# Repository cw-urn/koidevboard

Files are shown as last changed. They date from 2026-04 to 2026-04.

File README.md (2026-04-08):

# koidevboard

> What is this?
- koiboard, but the RP2040 development board version.
> How do you use it?
- Everybody knows how to use a devboard...
> Why did I make this?
- Boredom, and I thought it would be interesting and I'd learn from it. I did!

## 3D render
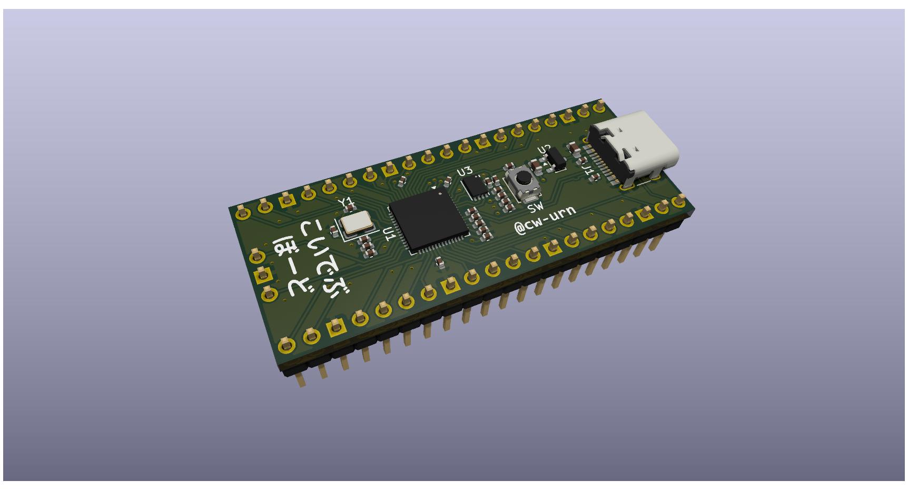
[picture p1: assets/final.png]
3D render


## PCB

### Layer 1
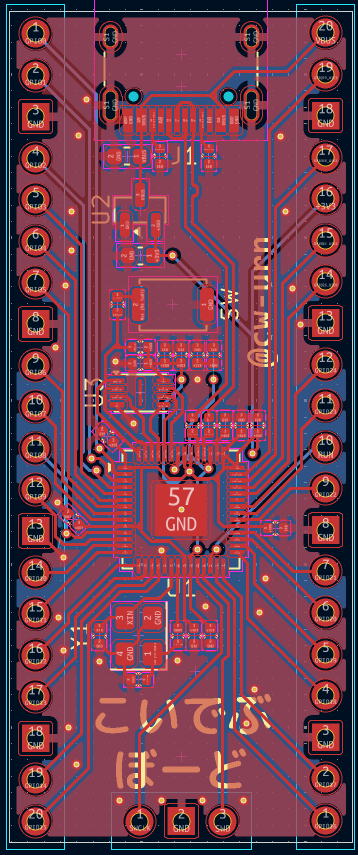
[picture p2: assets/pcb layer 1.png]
Layer 1


### Layer 2
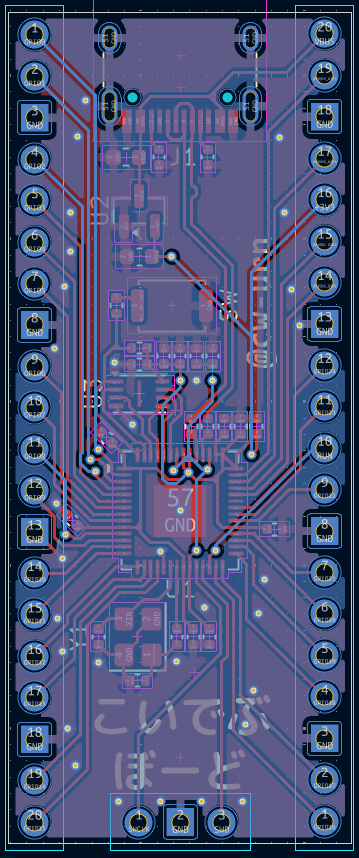
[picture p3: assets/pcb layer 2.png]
Layer 2


### Schematic
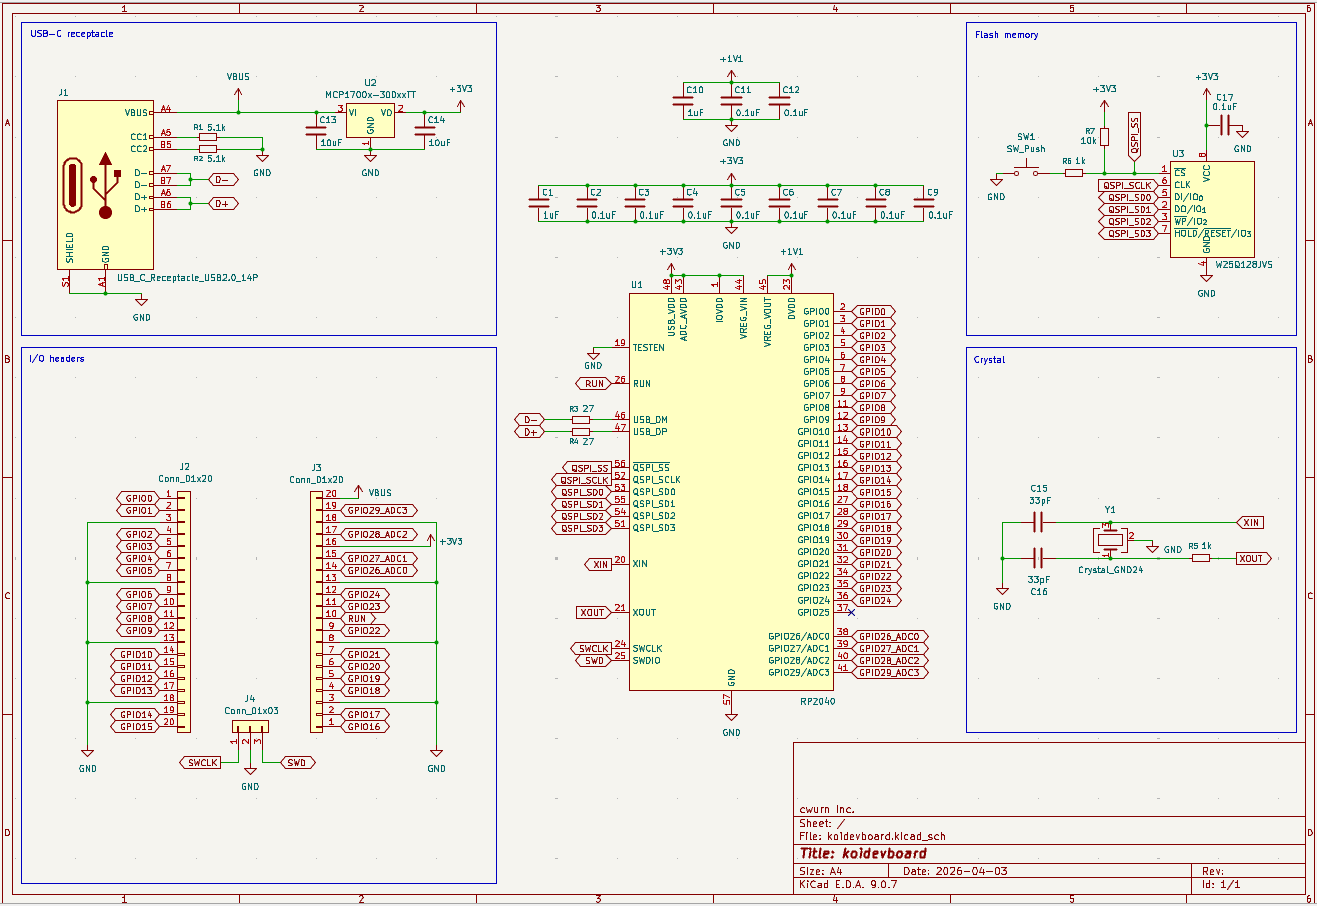
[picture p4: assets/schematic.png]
Schematic


## JLCPCB cart
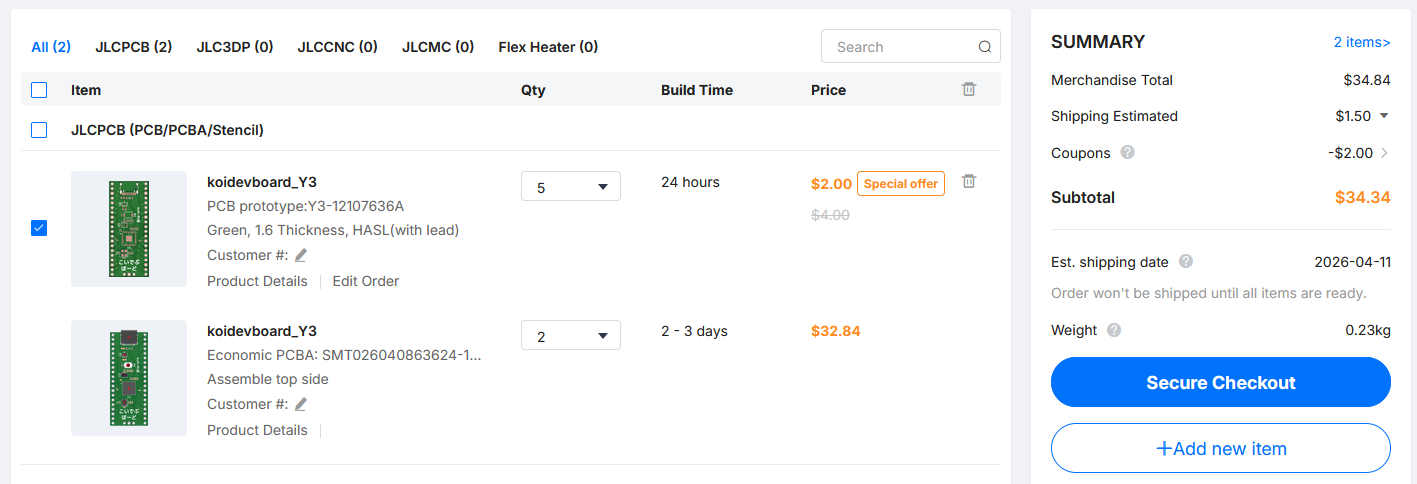
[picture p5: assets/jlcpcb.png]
JLCPCB cart


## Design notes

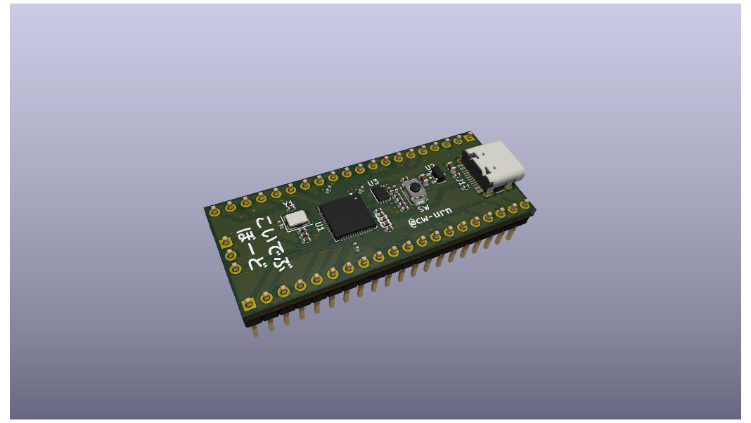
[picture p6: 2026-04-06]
pcb/src/3d render.png

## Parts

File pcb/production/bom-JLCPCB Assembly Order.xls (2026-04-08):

JLCPCB BOM Tool - BOM Matching
BOM name：bom-JLCPCB Assembly Order.xlsx |  |  | Download Time：2026-04-09 04:32:29 |  |  |  | * Our matching results are updated in real-time, but stock and prices may change. If it's been over 24 hours, please re-match before placing your order.
PCB Assembled Qty：5 |  |  | Est. Total Price：6.6379
Your BOM |  |  |  |  | Matched Parts |  |  |  |  |  |  | Order Information
Top Designator | Bottom Designator | Comment | Footprint | JLCPCB Part # | Matches | Part # | Manufacturer | Footprint | Description | Category | Warning | JLCPCB Part # | Product link | Lib Type | Qty | Source | Total Price ($)
C1,C10 |  | 1uF | 0402 |  | Select by System | CL05A105KA5NQNC | Samsung Electro-Mechanics | 0402 | 1uF 25V X5R ±10% 0402 Multilayer Ceramic Capacitors MLCC - SMD/SMT ROHS | Multilayer Ceramic Capacitors MLCC - SMD/SMT |  | C52923 | https://jlcpcb.com/partdetail/53938-CL05A105KA5NQNC/C52923 | Basic | 4 | 4 JLCPCB | 0.0164
C11,C12,C17,C2,C3,C4,C5,C6,C7,C8,C9 |  | 0.1uF | 0402 |  | Unconfirmed | CL05B104KO5NNNC | Samsung Electro-Mechanics | 0402 | 100nF 16V X7R ±10% 0402 Multilayer Ceramic Capacitors MLCC - SMD/SMT ROHS | Multilayer Ceramic Capacitors MLCC - SMD/SMT | 1.The comment (CL05B104KO5NNNC) of this part does not match the one (0.1uF) provided in your BOM. Please confirm; | C1525 | https://jlcpcb.com/partdetail/1877-CL05B104KO5NNNC/C1525 | Basic | 22 | 22 JLCPCB | 0.0286
C13,C14 |  | 10uF | 0603 |  | Select by System | CL10A106KP8NNNC | Samsung Electro-Mechanics | 0603 | 10V 10uF X5R ±10% 0603 Multilayer Ceramic Capacitors MLCC - SMD/SMT ROHS | Multilayer Ceramic Capacitors MLCC - SMD/SMT |  | C19702 | https://jlcpcb.com/partdetail/20411-CL10A106KP8NNNC/C19702 | Basic | 4 | 4 JLCPCB | 0.0316
C15,C16 |  | 33pF | 0402 |  | Select by System | 0402CG330J500NT | FH (Guangdong Fenghua Advanced Tech) | 0402 | 33pF 50V C0G ±5% 0402 Multilayer Ceramic Capacitors MLCC - SMD/SMT ROHS | Multilayer Ceramic Capacitors MLCC - SMD/SMT |  | C1562 | https://jlcpcb.com/partdetail/1914-0402CG330J500NT/C1562 | Basic | 4 | 4 JLCPCB | 0.0048
J1 |  | USB_C_Receptacle_USB2.0_14P | USB_C_Receptacle_HRO_TYPE-C-31-M-12 |  | Select by Customer | TYPE-C-31-M-12 | Korean Hroparts Elec | SMD | -30℃~+80℃ 1 10,000 cycles 16P 20V 5A 7.35mm Female Surface Mount, Right Angle Type-C SMD USB Connectors ROHS | USB Connectors |  | C165948 | https://jlcpcb.com/partdetail/Korean_HropartsElec-TYPE_C_31_M12/C165948 | Extended | 2 | 2 JLCPCB | 0.3654
R1,R2 |  | 5.1k | 0402 |  | Unconfirmed | 0402WGF5101TCE | UNI-ROYAL(Uniroyal Elec) | 0402 | -55℃~+155℃ 5.1kΩ 50V 62.5mW Thick Film Resistor ±1% ±100ppm/℃ 0402 Chip Resistor - Surface Mount ROHS | Chip Resistor - Surface Mount | 1.The comment (0402WGF5101TCE) of this part does not match the one (5.1k) provided in your BOM. Please confirm; | C25905 | https://jlcpcb.com/partdetail/26648-0402WGF5101TCE/C25905 | Basic | 4 | 4 JLCPCB | 0.0032
R3,R4 |  | 27 | 0402 |  | Unconfirmed | 0402WGF270JTCE | UNI-ROYAL(Uniroyal Elec) | 0402 | -55℃~+155℃ 27Ω 50V 62.5mW Thick Film Resistor ±1% ±100ppm/℃ 0402 Chip Resistor - Surface Mount ROHS | Chip Resistor - Surface Mount | 1.The comment (0402WGF270JTCE) of this part does not match the one (27) provided in your BOM. Please confirm; | C25100 | https://jlcpcb.com/partdetail/25843-0402WGF270JTCE/C25100 | Extended | 20 | 20 JLCPCB | 0.016
R5,R6 |  | 1k | 0402 |  | Unconfirmed | 0402WGF1001TCE | UNI-ROYAL(Uniroyal Elec) | 0402 | -55℃~+155℃ 1kΩ 50V 62.5mW Thick Film Resistor ±1% ±100ppm/℃ 0402 Chip Resistor - Surface Mount ROHS | Chip Resistor - Surface Mount | 1.The comment (0402WGF1001TCE) of this part does not match the one (1k) provided in your BOM. Please confirm; | C11702 | https://jlcpcb.com/partdetail/12256-0402WGF1001TCE/C11702 | Basic | 4 | 4 JLCPCB | 0.0028
R7 |  | 10k | 0402 |  | Unconfirmed | 0402WGF1002TCE | UNI-ROYAL(Uniroyal Elec) | 0402 | -55℃~+155℃ 10kΩ 50V 62.5mW Thick Film Resistor ±1% ±100ppm/℃ 0402 Chip Resistor - Surface Mount ROHS | Chip Resistor - Surface Mount | 1.The comment (0402WGF1002TCE) of this part does not match the one (10k) provided in your BOM. Please confirm; | C25744 | https://jlcpcb.com/partdetail/26487-0402WGF1002TCE/C25744 | Basic | 2 | 2 JLCPCB | 0.0024
SW |  | SW_Push | SW_Push_SPST_NO_Alps_SKRK |  | Select by Customer | TS-1088-AR02016 | XUNPU | SMD,4x3mm | -30℃~+80℃ 1.6N 100,000 cycles 12V 2mm 3mm 4mm 50mA Black Round Button SMD(SMT) Tab SPST Surface Mount,Vertical Without Bracket SMD,4x3mm Tactile Switches ROHS | Tactile Switches |  | C720477 | https://jlcpcb.com/partdetail/XUNPU-TS_1088AR02016/C720477 | Basic | 2 | 2 JLCPCB | 0.1078
U1 |  | RP2040 | QFN-56-1EP_7x7mm_P0.4mm_EP3.2x3.2mm |  | Select by Customer | RP2040 | Raspberry Pi | LQFN-56(7x7) | 12bit 133MHz 30 LQFN-56(7x7) Microcontrollers (MCU/MPU/SOC) ROHS | Microcontrollers (MCU/MPU/SOC) |  | C2040 | https://jlcpcb.com/partdetail/RaspberryPi-RP2040/C2040 | Extended | 2 | 2 JLCPCB | 1.948
U2 |  | MCP1700x-300xxTT | SOT-23 |  | Select by Customer | MCP1700T-3302E/TT | Microchip Tech | SOT-23 | -40℃~+125℃@(Tj) 1 1.6uA 178mV@(250mA) 250mA 3.3V 44dB@(100Hz) 6V Fixed Over Temperature Protection、Short Circuit Protection Positive SOT-23 Voltage Regulators - Linear, Low Drop Out (LDO) Regulators ROHS | Voltage Regulators - Linear, Low Drop Out (LDO) Regulators |  | C39051 | https://jlcpcb.com/partdetail/MicrochipTech-MCP1700T_3302ETT/C39051 | Extended | 5 | 5 JLCPCB | 1.8795
U3 |  | W25Q128JVS | Winbond_USON-8-1EP_3x2mm_P0.5mm_EP0.2x1.6mm |  | Select by Customer | W25Q16JVUXIQ | Winbond Elec | USON-8-EP(2x3) | -40℃~+85℃ 100,000 cycles 10uA 133MHz 16Mbit 2.7V~3.6V 20 Years 3ms SPI USON-8-EP(2x3) NOR FLASH ROHS | NOR FLASH | 1.The comment (W25Q16JVUXIQ) of this part does not match the one (W25Q128JVS) provided in your BOM. Please confirm; | C2843335 | https://jlcpcb.com/partdetail/WinbondElec-W25Q16JVUXIQ/C2843335 | Extended | 2 | 2 JLCPCB | 2.085
Y1 |  | Crystal_GND24 | Crystal_SMD_3225-4Pin_3.2x2.5mm |  | Select by Customer | X322512MSB4SI | YXC Crystal Oscillators | SMD3225-4P | -40℃~+85℃ 12MHz 20pF Crystal Oscillator ±10ppm ±20ppm SMD3225-4P Crystals ROHS | Crystals |  | C9002 | https://jlcpcb.com/partdetail/YXC_CrystalOscillators-X322512MSB4SI/C9002 | Basic | 2 | 2 JLCPCB | 0.1464

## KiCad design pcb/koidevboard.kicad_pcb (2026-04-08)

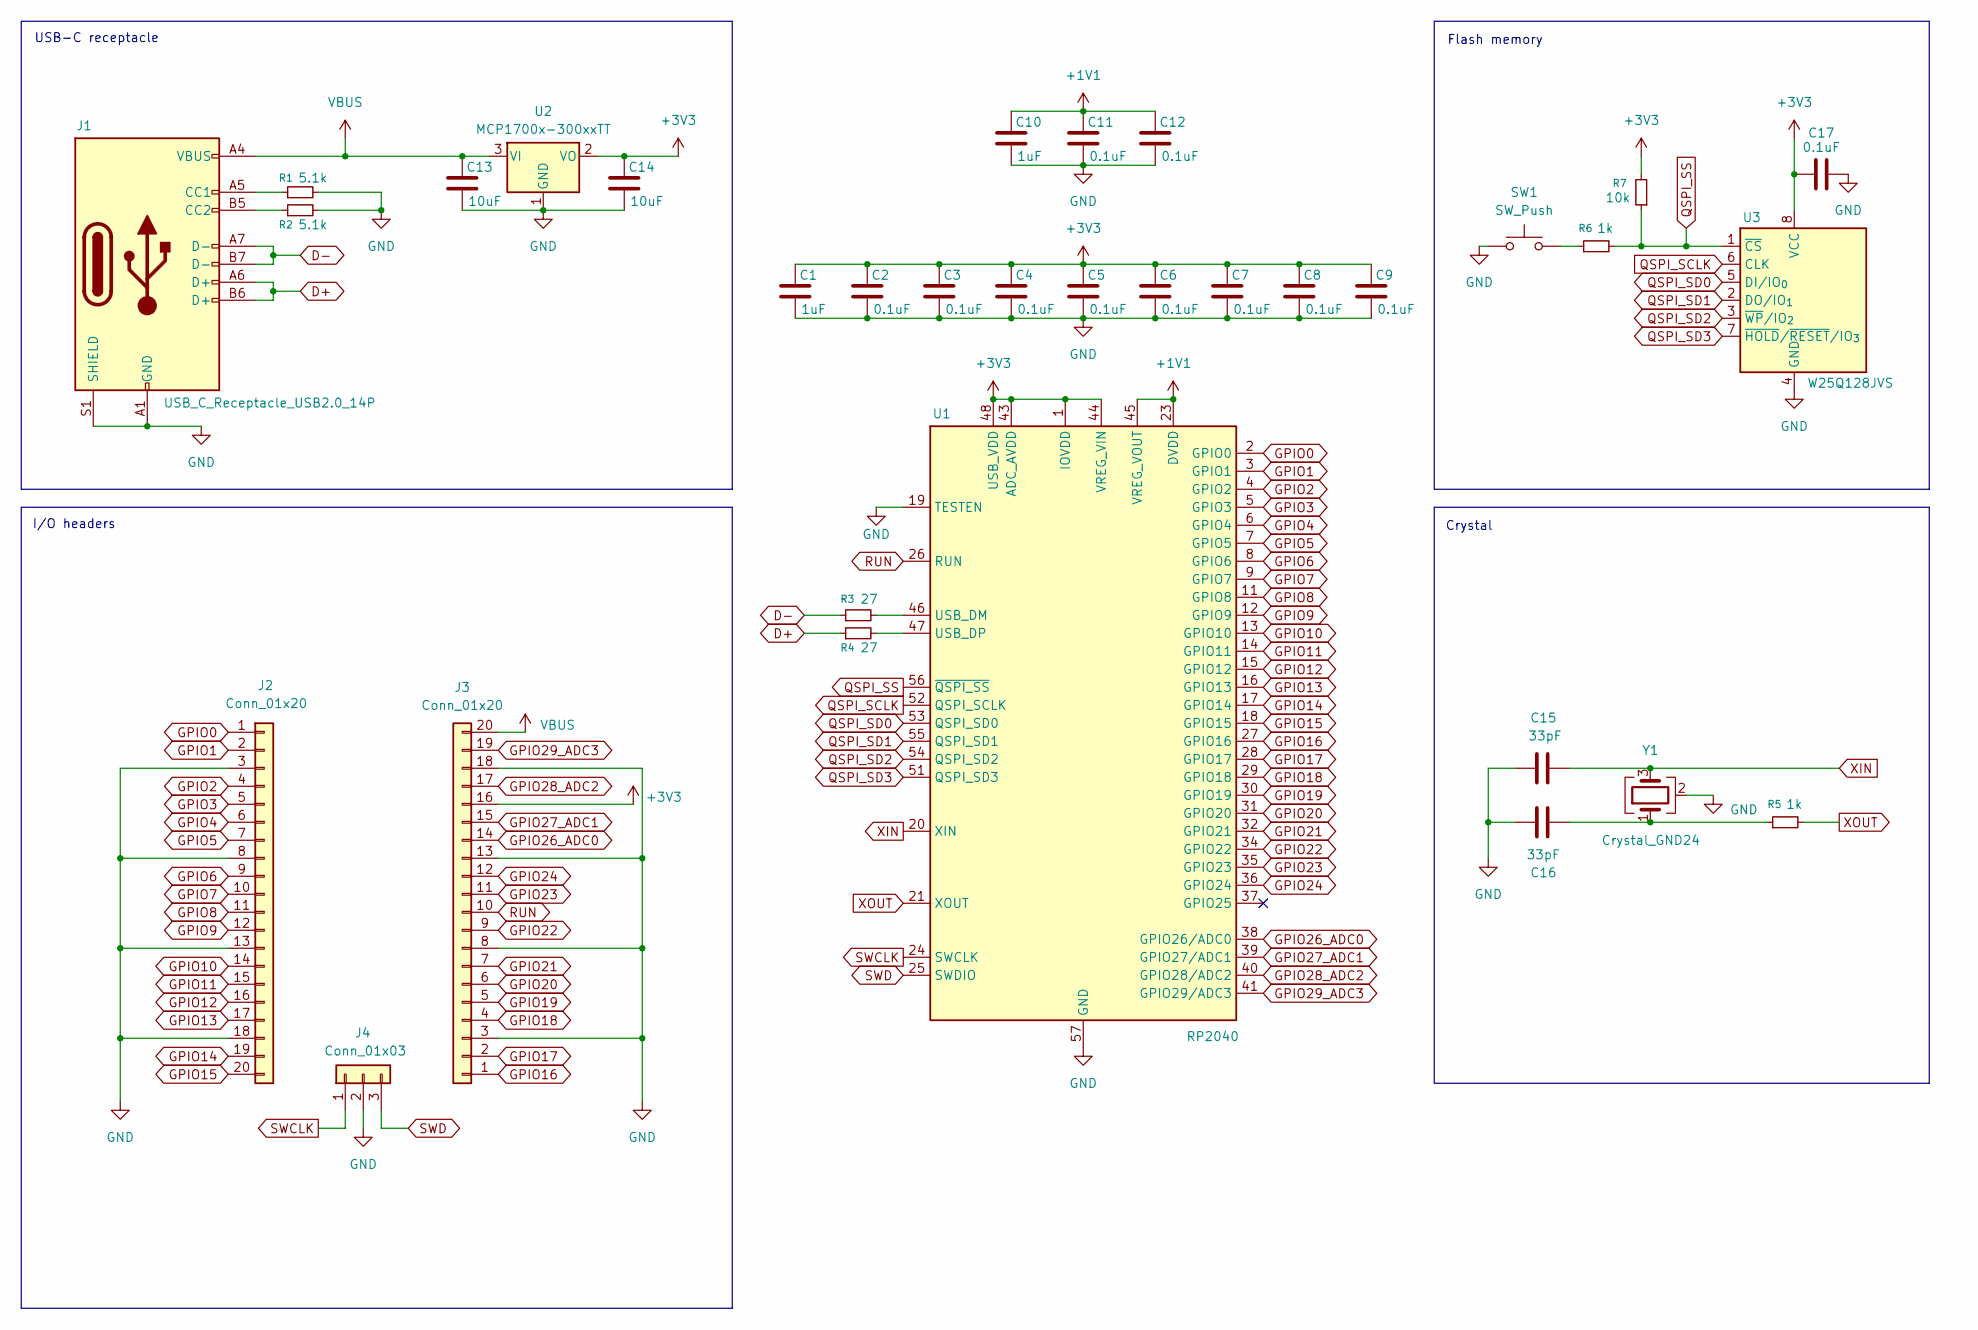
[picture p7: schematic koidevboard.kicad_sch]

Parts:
C1, C10: 1uF; C_0402_1005Metric
C2, C3, C4, C5, C6, C7, C8, C9, C11, C12, C17: 0.1uF; C_0402_1005Metric
C13, C14: 10uF; C_0603_1608Metric
C15, C16: 33pF; C_0402_1005Metric
J1: USB_C_Receptacle_USB2.0_14P; USB_C_Receptacle_HRO_TYPE-C-31-M-12
J2, J3: Conn_01x20; PinHeader_1x20_P2.54mm_Vertical
J4: Conn_01x03; PinHeader_1x03_P2.54mm_Vertical
R1, R2: 5.1k; C_0402_1005Metric
R3, R4: 27; C_0402_1005Metric
R5, R6: 1k; C_0402_1005Metric
R7: 10k; C_0402_1005Metric
SW1: SW_Push; SW_Push_SPST_NO_Alps_SKRK
U1: RP2040; QFN-56-1EP_7x7mm_P0.4mm_EP3.2x3.2mm
U2: MCP1700x-300xxTT; SOT-23
U3: W25Q128JVS; Winbond_USON-8-1EP_3x2mm_P0.5mm_EP0.2x1.6mm
Y1: Crystal_GND24; Crystal_SMD_3225-4Pin_3.2x2.5mm

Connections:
+1V1: C10.1, C11.1, C12.1, U1.23 (DVDD), U1.45 (VREG_VOUT), U1.50 (DVDD)
+3V3: C1.1, C2.1, C3.1, C4.1, C5.1, C6.1, C7.1, C8.1, C9.1, C14.1, C17.1, J3.16, R7.2, U1.1 (IOVDD), U1.10 (IOVDD), U1.22 (IOVDD), U1.33 (IOVDD), U1.42 (IOVDD), U1.43 (ADC_AVDD), U1.44 (VREG_VIN), U1.48 (USB_VDD), U1.49 (IOVDD), U2.2 (VO), U3.8 (VCC)
D+: J1.A6 (D+), J1.B6 (D+), R4.1
D-: J1.A7 (D-), J1.B7 (D-), R3.1
GND: C1.2, C2.2, C3.2, C4.2, C5.2, C6.2, C7.2, C8.2, C9.2, C10.2, C11.2, C12.2, C13.2, C14.2, C15.2, C16.2, C17.2, J1.A1 (GND), J1.A12 (GND), J1.B1 (GND), J1.B12 (GND), J1.S1 (SHIELD), J2.3, J2.8, J2.13, J2.18, J3.3, J3.8, J3.13, J3.18, J4.2, R1.2, R2.2, SW1.1, U1.19 (TESTEN), U1.57 (GND), U2.1 (GND), U3.4 (GND), Y1.2 (G), Y1.4 (G); also elsewhere on the board
GPIO0: J2.1, U1.2 (GPIO0)
GPIO1: J2.2, U1.3 (GPIO1)
GPIO2: J2.4, U1.4 (GPIO2)
GPIO3: J2.5, U1.5 (GPIO3)
GPIO4: J2.6, U1.6 (GPIO4)
GPIO5: J2.7, U1.7 (GPIO5)
GPIO6: J2.9, U1.8 (GPIO6)
GPIO7: J2.10, U1.9 (GPIO7)
GPIO8: J2.11, U1.11 (GPIO8)
GPIO9: J2.12, U1.12 (GPIO9)
GPIO10: J2.14, U1.13 (GPIO10)
GPIO11: J2.15, U1.14 (GPIO11)
GPIO12: J2.16, U1.15 (GPIO12)
GPIO13: J2.17, U1.16 (GPIO13)
GPIO14: J2.19, U1.17 (GPIO14)
GPIO15: J2.20, U1.18 (GPIO15)
GPIO16: J3.1, U1.27 (GPIO16)
GPIO17: J3.2, U1.28 (GPIO17)
GPIO18: J3.4, U1.29 (GPIO18)
GPIO19: J3.5, U1.30 (GPIO19)
GPIO20: J3.6, U1.31 (GPIO20)
GPIO21: J3.7, U1.32 (GPIO21)
GPIO22: J3.9, U1.34 (GPIO22)
GPIO23: J3.11, U1.35 (GPIO23)
GPIO24: J3.12, U1.36 (GPIO24)
GPIO26_ADC0: J3.14, U1.38 (GPIO26/ADC0)
GPIO27_ADC1: J3.15, U1.39 (GPIO27/ADC1)
GPIO28_ADC2: J3.17, U1.40 (GPIO28/ADC2)
GPIO29_ADC3: J3.19, U1.41 (GPIO29/ADC3)
unnamed: C16.1, R5.1, Y1.1
unnamed: J1.A5 (CC1), R1.1
unnamed: J1.B5 (CC2), R2.1
unnamed 37: R6.1, SW1.2; also elsewhere on the board
unnamed: R3.2, U1.46 (USB_DM)
unnamed: R4.2, U1.47 (USB_DP)
QSPI_SCLK: U1.52 (QSPI_SCLK), U3.6 (CLK)
QSPI_SD0: U1.53 (QSPI_SD0), U3.5 (DI/IO_{0})
QSPI_SD1: U1.55 (QSPI_SD1), U3.2 (DO/IO_{1})
QSPI_SD2: U1.54 (QSPI_SD2), U3.3 (~WP/IO_{2})
QSPI_SD3: U1.51 (QSPI_SD3), U3.7 (~HOLD/~RESET/IO_{3})
QSPI_SS: R6.2, R7.1, U1.56 (~QSPI_SS), U3.1 (~CS)
RUN: J3.10, U1.26 (RUN)
SWCLK: J4.1, U1.24 (SWCLK)
SWD: J4.3, U1.25 (SWDIO)
VBUS: C13.1, J1.A4 (VBUS), J1.A9 (VBUS), J1.B4 (VBUS), J1.B9 (VBUS), J3.20, U2.3 (VI)
XIN: C15.1, U1.20 (XIN), Y1.3
XOUT: R5.2, U1.21 (XOUT)

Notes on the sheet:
Flash memory
USB-C receptacle
I/O headers
Crystal

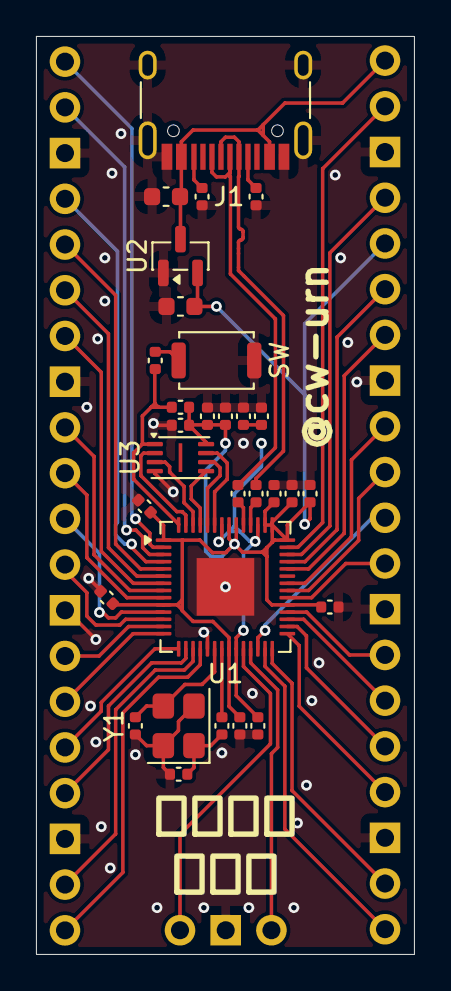
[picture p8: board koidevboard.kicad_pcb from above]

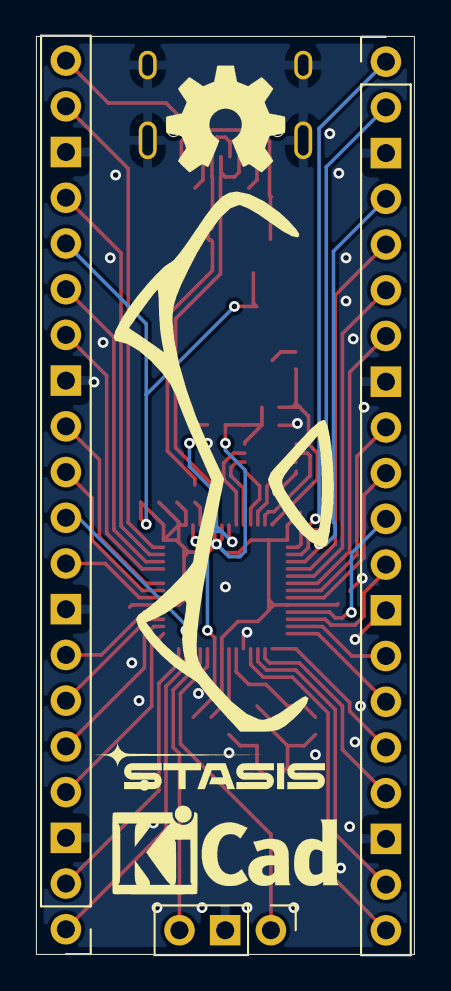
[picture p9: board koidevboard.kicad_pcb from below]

Board: 2 copper layers, 21.0 x 51.0 mm, 33 parts (3 on the bottom side), 52 nets.

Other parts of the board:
SW: SW_Push; SW_Push_SPST_NO_Alps_SKRK

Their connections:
GND: SW.1; also elsewhere on the board
unnamed 37: SW.2; also elsewhere on the board
